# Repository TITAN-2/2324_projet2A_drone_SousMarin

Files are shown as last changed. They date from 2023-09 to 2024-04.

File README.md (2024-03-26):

# Projet de Drone Sous-marin - TITAN II - 2e Année ENSEA

## Description du Projet

Ce projet de deuxième année d'école d'ingénieur en électronique informatique vise à concevoir et développer un drone sous-marin contrôlable à distance. L'objectif de ce projet est de récupérer des objets dans le fond de l'étang de Cergy : plus précisement des lunettes de plongée. 
Le drone sera équipé de deux moteurs submersibles afin de propulser l'ensemble sous l'eau, de différents capteurs explicités plus tard, de seringues en guise de ballast, et finalement d'une STM32 couplée a une Raspeberry Pi. 

Le drone sera équipé de capteurs de pression et d'une centrale inertielle, connectés à une carte STM32. La communication entre les capteurs, les moteurs et les utilisateurs sera gérée par la STM32, tandis qu'une Raspberry Pi sera utilisée pour recevoir les informations des utilisateurs, héberger un serveur, et afficher une interface homme-machine (IHM) avec un flux vidéo provenant des caméras Pi.

## Fonctionnalités Principales

1. **STM32 pour la Gestion des Capteurs et des Moteurs**
   - La carte STM32 sera responsable de la communication avec les capteurs.
   - Elle assurera également le contrôle des moteurs en réponse aux commandes des utilisateurs.

2. **Raspberry Pi pour l'Interface Utilisateur**
   - La Raspberry Pi recevra les informations des utilisateurs.
   - Elle hébergera un serveur qui affichera le flux vidéo des caméras Pi et permettra aux utilisateurs d'envoyer des commandes au drone sous-marin.

3. **UART STM32 et la Raspberry Pi**
   - L'UART sera bidirectionnel
   - La Rasberry communiquera vers la STM32 les commandes utilisateurs reçu du serveur.
   - La STM32 communiquera vers la Raspberry les informations des différents capteurs (position, vitesse, niveau de batterie...)

## Configuration Matérielle

- **STM32**
  - Pin A0: PWM Moteur Gauche
  - Pin A1: PWM Moteur Droit
  - Pin RX: Reception de l'UART Raspberry
  - Pin TX: Transmission via UART vers Raspberry

- **Raspberry Pi**
  - A définir

- **Caméras Pi**
  - Voir le HowTo (a définir également)

## Installation et Exécution

1. Cloner le dépôt du projet sur la machine hôte.
   ```bash
   git clone https://github.com/votre-utilisateur/projet-drone-sous-marin.git
## Tester les parties indépendemments

[LA RECEPTION STM32](/RECEPTION_UART_H7A3ZIQ/HOWTO.md)

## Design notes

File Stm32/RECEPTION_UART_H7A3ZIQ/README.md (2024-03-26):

# TESTER LA RECEPTION STM32

## Installation de minicom
### Pour MAC
Installation avec HomeBrew :

```
brew install minicom
exec zsh
```

## Utilisation de minicom
 - **Envoie** de symbole, ici on se connecte au Raspberry Pi : 
```
minicom -b 115200 -o -D /dev/ttyS0 
```
>[!NOTE]
>Vous pouvez envoyer des commandes personnaliser avec  `echo 'votre message' < /dev/ttyS0`

 - **Reception** de symbole, ici sur le terminal connecter a la STM32
```
minicom -b 115200 -D /dev/tty.usbmodem1303
```
>[!NOTE]
> Remplacer le .usbmodem1303 par ce qui convient

## BRANCHEMENT SUR STM32
### SUR LA H7A3
On banche raspberry (TX : pin 6) sur la STM32 (RX : PD0, uart4)

## DETAILS DE COMMUNICATION
### RECEPTION | Procédure "maison"
On recoit un message de 8 octet de la forme:
- 2 bits : Check Header --> 0xFFFE
- 1 bit : Check Length --> 8
- 5 bits : Message --> thrust | angle | depth | paquetNumber
- 1 bit : Check Sum --> méthode XOR
- x bits : RPI Response --> Renvoie un message de confirmation ou non à la Raspberry

```
stty -F /dev/ttyS0 115200
echo -ne "\xFF\xFE\x09\x53\x1A\x64\x10\xFF\xCB" > /dev/ttyS0
```
```
stty -F /dev/ttyS0 115200
echo -ne "\xFF\xFE\x09\x53\x2D\x64\x10\xFF\xFD" > /dev/ttyS0
```
### RECEPTION | DYNAMIXEL 2.0
- [ ] https://github.com/TITAN-2/2324_projet2A_drone_SousMarin/issues/2
> Réaliser le même protocole que celui possiblement utilisé par les servo-moteurs. 1 pierre 2 coups.

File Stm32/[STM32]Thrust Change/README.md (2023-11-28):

# Modifier le thrust des moteurs

## Description 

Le but est de pouvoir modifier la puissance des moteurs controlés par un ASC, pour cela on envoie un PWM de rapport cyclique variant.
Il existe un protocole pour démarrer les ASC : 

**Start Protocole**

 - Envoyer un signal périodique créneaux de 50Hz avec un temps haut de 1ms, cela doit correspondre à notre rapport cyclique le plus faible ie \alpha = 0
 - Envoyer ce signal durant 1s
 - Modifier, ensuite, le temps haut à 2ms, cela correspond à notre rapport cyclique le plus élevée ie \alpha = 1
 - Envoyer ce signal durant 1s

**End Protocole**

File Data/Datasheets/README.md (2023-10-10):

# 2324_projet2A_drone_sous-marin

Poids à vide de la structure du sous-marin : 891 grammes

Point de flotaison de la structure du sous-marin : 3,120kg

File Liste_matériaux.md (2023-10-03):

Liste matériaux
- seringues 50 mL x4
- moteur

- caméra
- LED

- batteries NimH

- cylindre PVC

- STM32
- Raspberry

- Propulseur

- Capteurs pression hydraulique
- Capteur de proximité laser
- Capteur de température
- Centrale inertielle

- bouée avec MODEM
- Téléphone

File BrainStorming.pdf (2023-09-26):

Ébauche du cahier des charges:

- Énergie limité car syst embarqué
- Immersion du module donc étanchéité nécessaire
- Appareil pour récupérer un masque
- Sûrement une caméra à prévoir

Liens utiles:

Projet Sous-Marin ECAM (https://www.instructables.com/ECAM-Submarine/)

Question:

Structure à imprimer en 3D → Comment créer les fichiers à communiquer à l'imprimante 3D :

Cahier des charges:
- Construire un sous marin;
- Être capable d’avancer dans l’eau;
- Gérer la profondeur du drone;
- Contrôler les mouvements du drone;
- Être commandable depuis la terre ferme;
- Transmettre des informations (vidéo, profondeur) du drone vers la terre ferme
- Récupérer les lunettes de Monsieur Fiack au fond des étangs.

Contraintes:
- Milieu dans lequel est le drone: Eau (étanchéité);
- Rocher au fond, algues;
- Poids du sous marin (le faire remonter);
- Pression;
- Faible propagation des OEM;
- Capture vidéo + Faible luminosité au fond de l’étang;
- Transmission vidéo (direct, faible latence);
●

Les objectifs envisagés face à ces contraintes:

- Rendre le drone étanche et solide;

- Gérer la profondeur pour éviter rocher et algues;
- Connaître le point d’équilibre pour faire remonter le robot;
- Contrôler que les éléments qui résistent à la pression de l’eau;
- Gérer la communication entre le drone et nous;
- Gérer la consommation en énergie et comment transmettre l’énergie
- Éclairer le fond des étangs et capturer avec une caméra le fonds des étangs;
- Gérer la transmission vidéo en direct;

Solutions technologique:
- Choix des matériaux + cylindre si impression 3D: Pas plexiglasse car risque explosion;
- Pour le faire couler: Ballastes pour gérer la profondeur et l’équilibre autour du cylindre + sable au fond du sous marin pour qu’il reste droit et qu’il coule.
- Gyroscope pour gérer l’équilibre du drone
- Accéléromètre pour gérer la vitesse
- Laser ou capteur de pression ou de position pour gérer l’altitude
- Partie Énergique: mettre une batterie dans le sous marin;
- Pour le faire avancer: Hélices présentent sur l’ancien robot, aimants, pompes aquarium
- Pour le faire remonter: Ballons avec Timer ou Corde.
- Connexion entre nous et le drone: Bouée attachée au robot avec antenne réceptrice ou ondes radios (sonnar).
- Contrôler les mouvements du drone: PCB + Raspberry Pi avec un code pour d’abord que le drone fasse 10m.
- Trouver les lunettes de Monsieur Fiack: Caméra + Bras articulé ou crochet.
- Éclairer le fond des étangs: LED

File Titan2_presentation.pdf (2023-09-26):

# TITAN

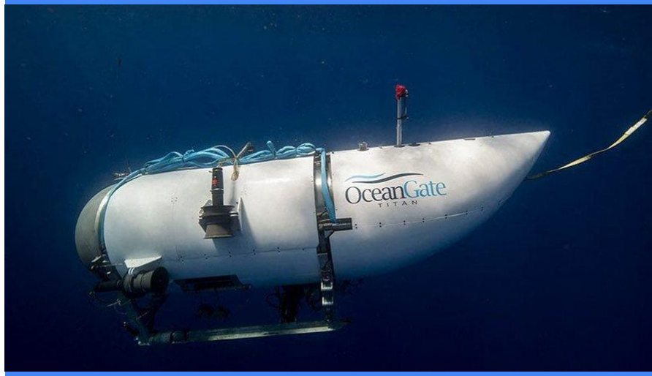
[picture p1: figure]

# Le drone Sous Marin qui ne

prendra pas l’eau.

II

# INTRODUCTION

2

# INTRODUCTION

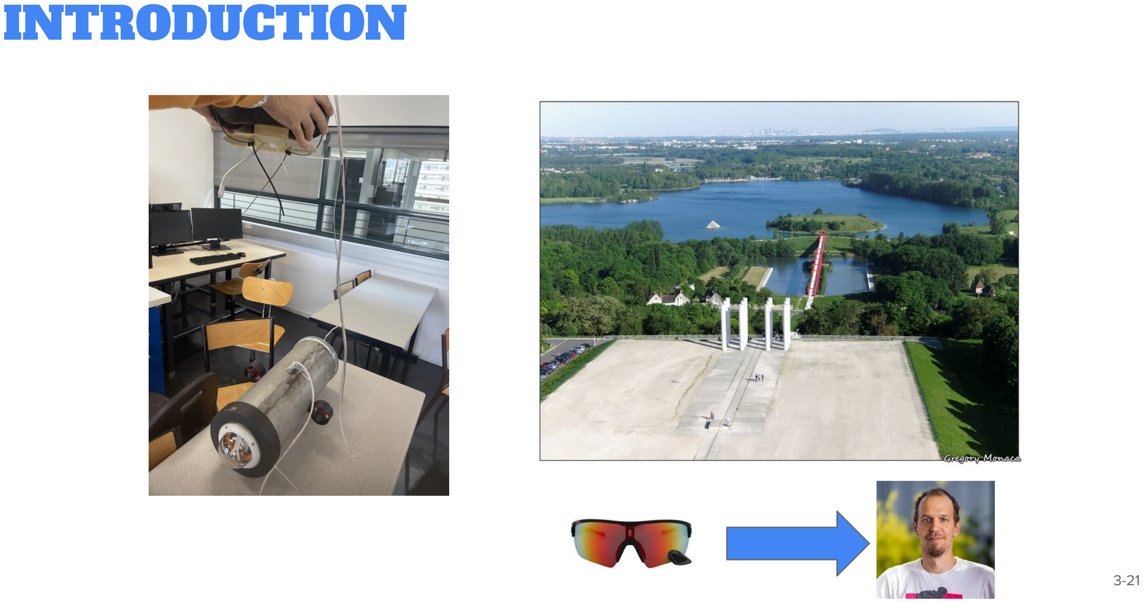
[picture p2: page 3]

# ÉTAT DE L’ART

4

# ÉTAT DE L’ART

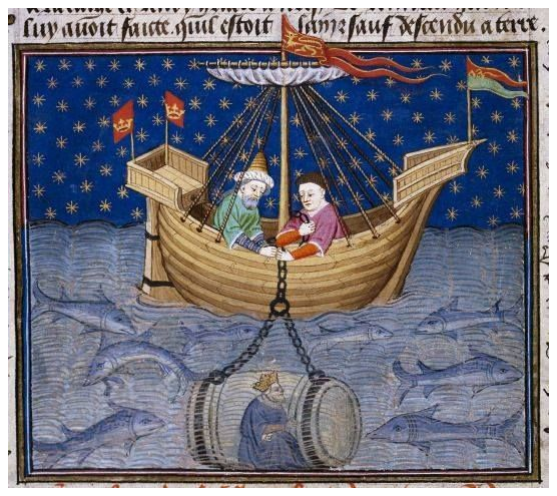
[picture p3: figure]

### 1ère cloche à plonger : tonneau d’Alexandre

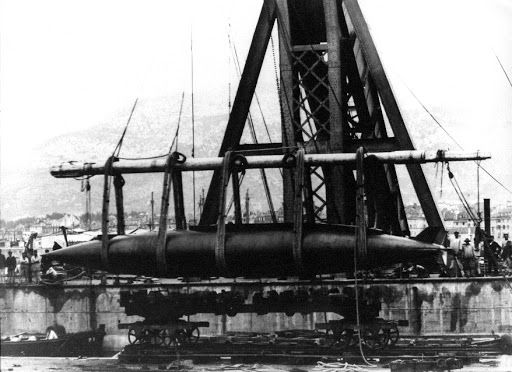
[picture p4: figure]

### 1887: Le gymnote, premier vrai sous-marin propulsé par un moteur électrique de 50 chevaux, atteint 8 noeuds en surface, 4 en plongée

### 1904: Le Narval, équipé d’un périscope et de ballasts externes,équipé d’une

propulsion mixte: machine à vapeur en surface, moteur électrique en plongée.

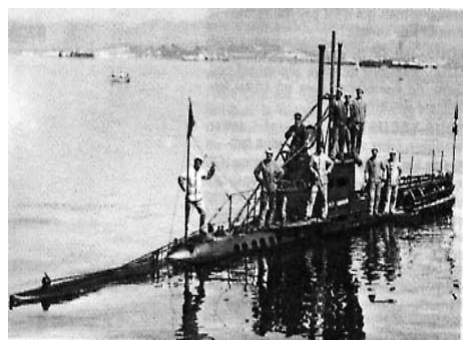
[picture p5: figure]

### 1914: Les submersibles fonctionnant grâce à une propulsion Diesel-électrique Une

batterie d’accumulateurs alimente un moteur électrique de propulsion.

1950: La propulsion nucléaire apparaît à bord des sous-marins,

# ÉTAT DE L’ART

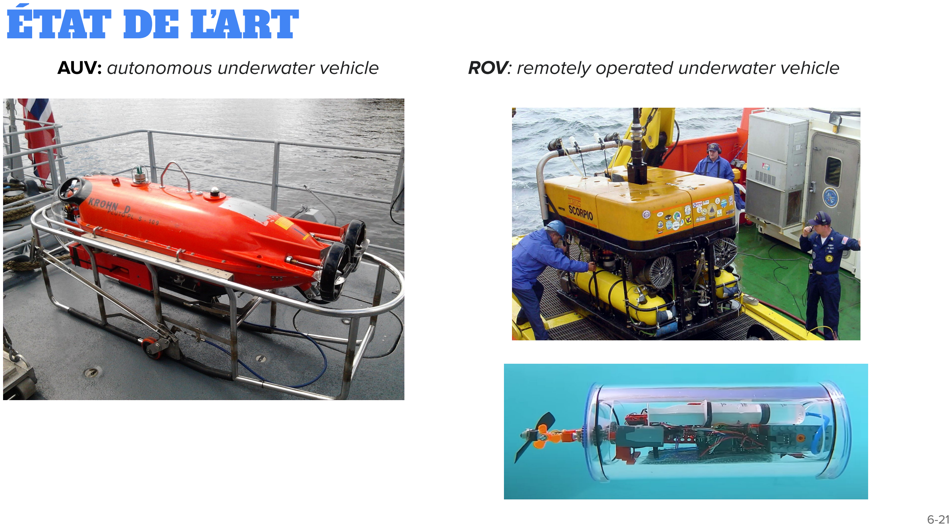
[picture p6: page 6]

AUV: autonomous underwater vehicle | ROV: remotely operated underwater vehicle

# CAHIER DES CHARGES

7

# CAHIER DES CHARGES

Fonctionnalités | Contraintes
F1 Être un système embarqué | Énergie limitée
F1.1 Être capable d’avancer dans l’eau | Milieu aquatique
F1.2 Gérer la profondeur du drone | C1 Présence de rocher au fond et d’algues C2 Poids du sous marin C3 Pression
F1.3 Être commandable depuis la terre ferme | C1 Faible propagation dans l’eau des OEM C2 Allure et orientation du drone variable

F2 Récupérer les lunettes de Monsieur Fiack au fond des étangs

F2.1 Visualiser le fond des étangs | C1 Capture vidéo C2 Faible luminosité au fond de l’étang

F2.2 Transmettre des informations du drone vers la terre
ferme

C1 Transmission vidéo en direct (ou faible latence)
C2 Transmission de multiple type de donnée (profondeur,
vitesse…) | 8-21

# OBJECTIFS ENVISAGÉS

9

# OBJECTIFS ENVISAGÉS

Contraintes | Objectifs
Énergie limitée | Choisir une source d’énergie adéquat Limiter l’utilisation de matériel énergivore
Milieu aquatique | Rendre le drone étanche
C1 Présence de rocher au fond et d’algues C2 Poids du sous marin C3 Pression | Connaître la profondeur de navigation Maîtriser le point de flottaison Utiliser des matériaux capable de supporter une légère pression
C1 Faible propagation dans l’eau des OEM C2 Allure et orientation du drone variable | Communiquer au drone des instructions intelligibles Connaître la vitesse et la position angulaire du drone
C1 Capture vidéo C2 Faible luminosité au fond de l’étang | Capturer le fonds des étangs Éclairer le fond des étangs
C1 Transmission vidéo en direct (ou faible latence) C2 Transmission de multiple type de donnée (profondeur, vitesse) | Communiquer à l’utilisateur des données en direct

# SOLUTIONS TECHNOLOGIQUES

11

# SOLUTIONS TECHNOLOGIQUES

OBJECTIFS CONCERNÉS : | Choisir une source d’énergie adéquat

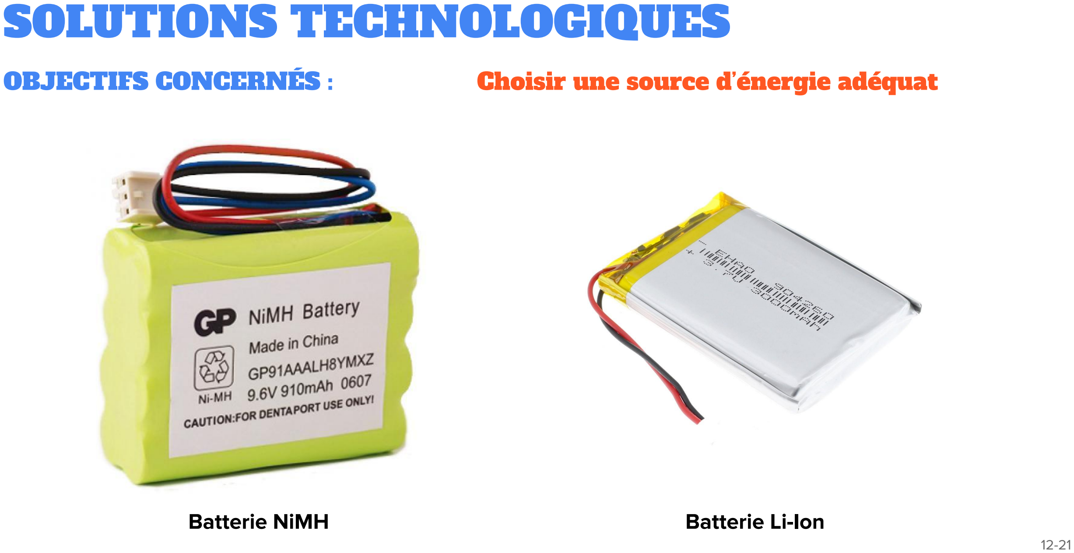
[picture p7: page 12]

Batterie NiMH | Batterie Li-Ion

# SOLUTIONS TECHNOLOGIQUES

OBJECTIFS CONCERNÉS : | Rendre le drone étanche & Utiliser des matériaux capable de supporter une légère pression

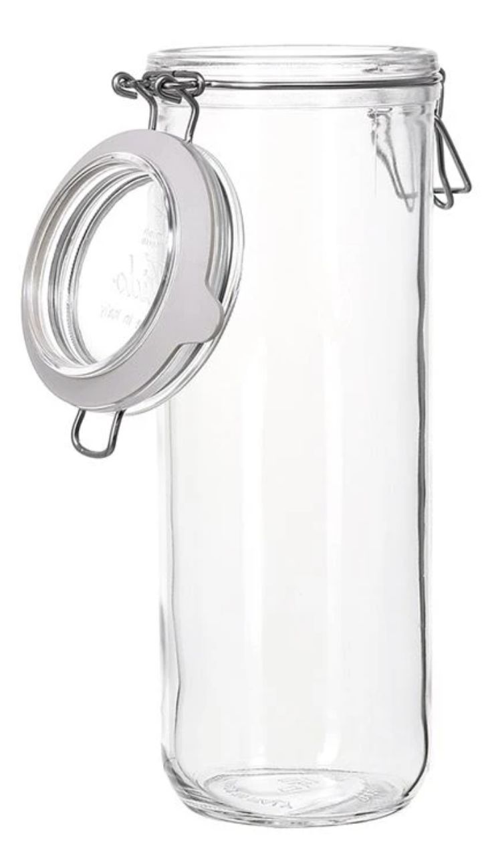
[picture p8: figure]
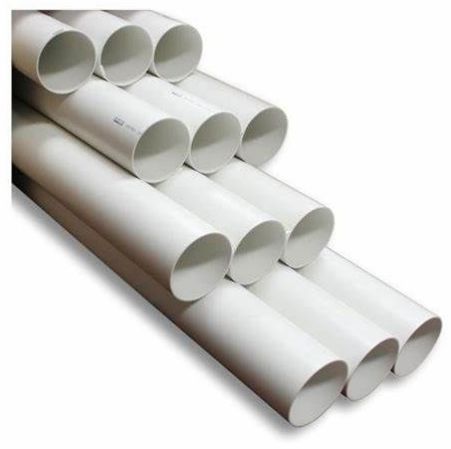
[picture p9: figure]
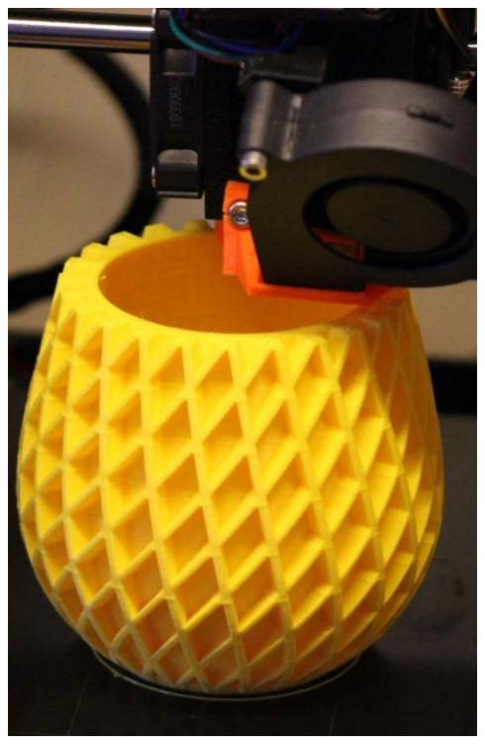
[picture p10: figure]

Bocal couvercle mécanique | PVC | Impression 3D

# SOLUTIONS TECHNOLOGIQUES

OBJECTIFS CONCERNÉS : | Connaître la profondeur de navigation

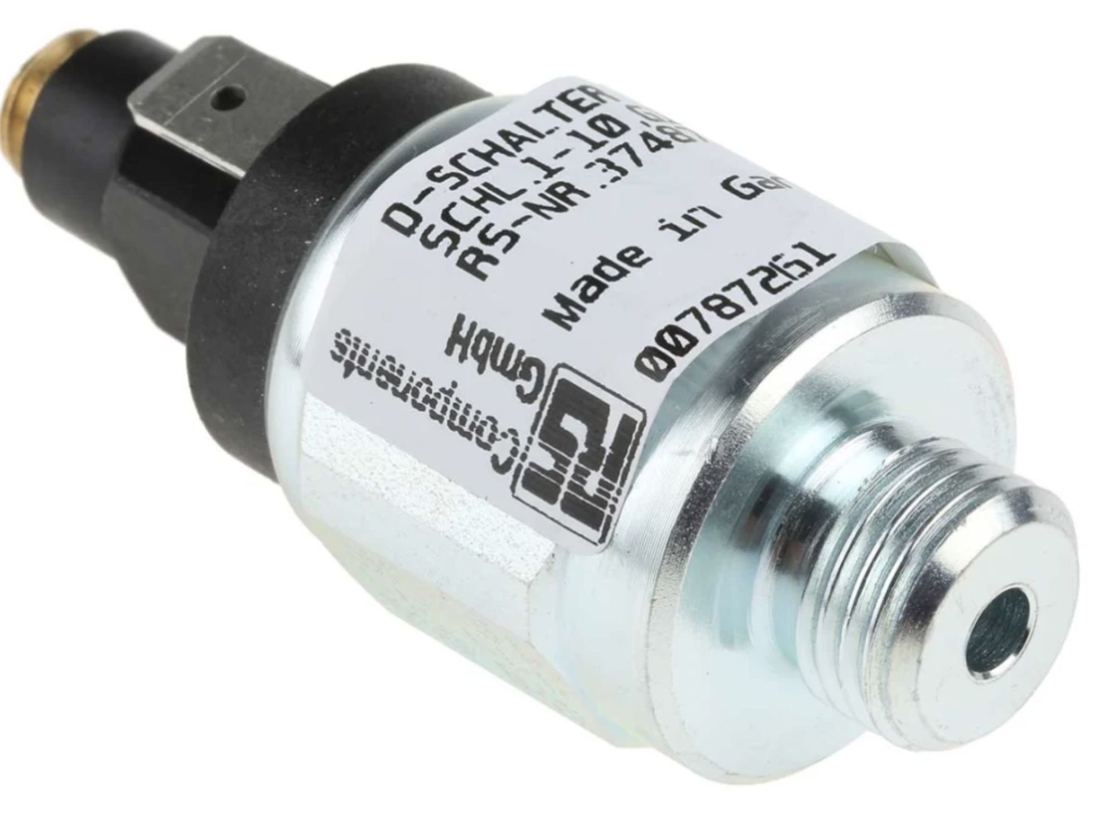
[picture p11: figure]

### Capteur pression hydraulique

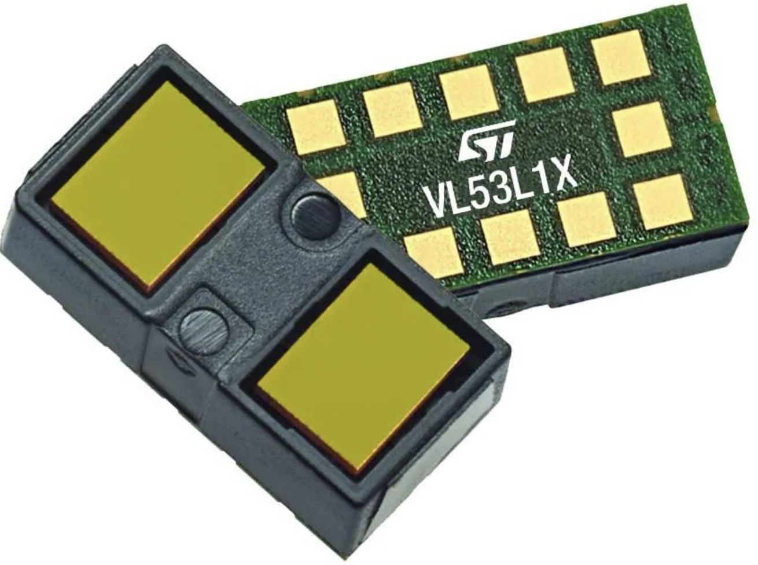
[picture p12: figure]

### Capteur de proximité laser

# SOLUTIONS TECHNOLOGIQUES

OBJECTIFS CONCERNÉS : | Faire avancer le drone sous-marin

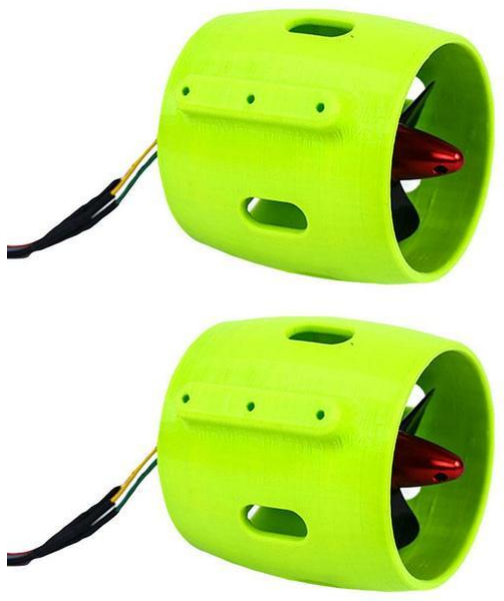
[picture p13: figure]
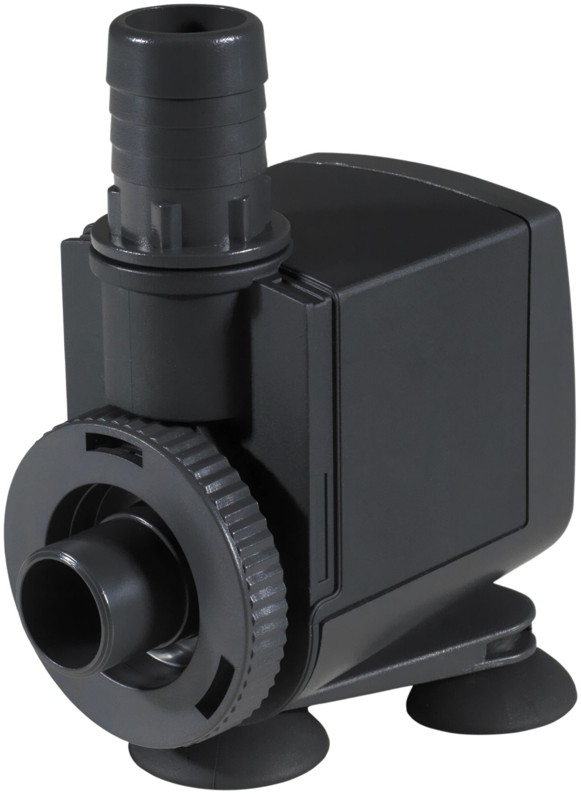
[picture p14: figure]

Propulseur sous marin | Pompe aquarium

# SOLUTIONS TECHNOLOGIQUES

OBJECTIFS CONCERNÉS : | Maîtriser le point de flottaison

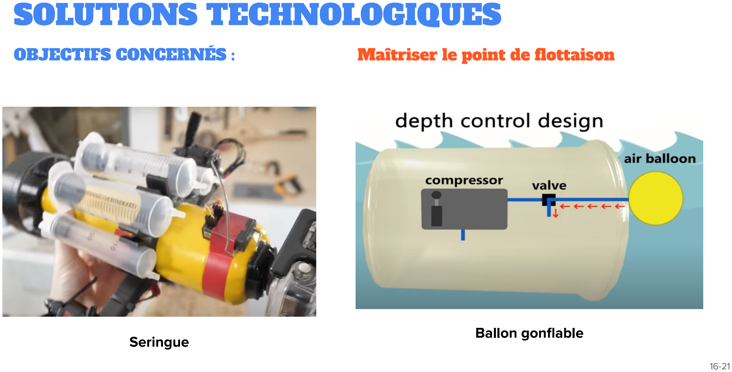
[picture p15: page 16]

### Seringue

### Ballon gonflable

# SOLUTIONS TECHNOLOGIQUES

# OBJECTIFS CONCERNÉS : Connaître la vitesse et la position angulaire du drone

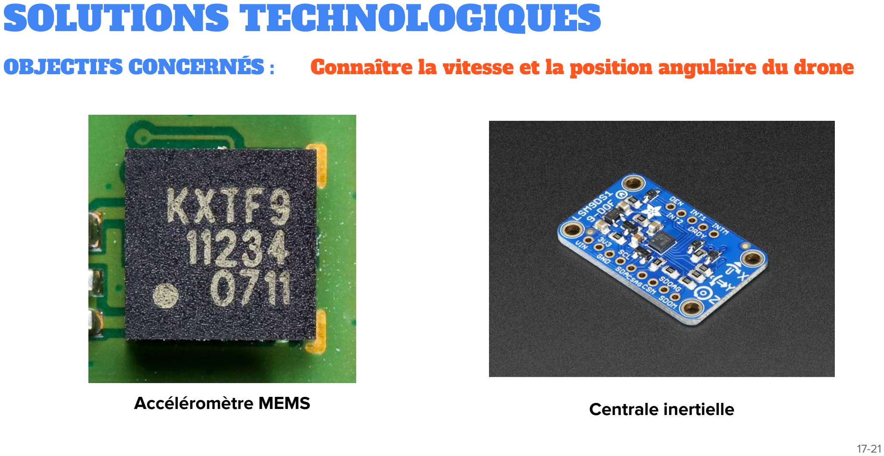
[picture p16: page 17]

Accéléromètre MEMS | Centrale inertielle

# SOLUTIONS TECHNOLOGIQUES

OBJECTIFS CONCERNÉS : | Capturer le fond des étangs

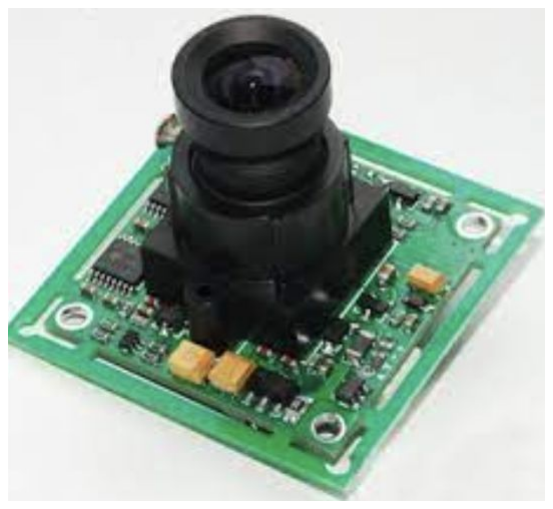
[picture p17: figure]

### STM32 Caméra

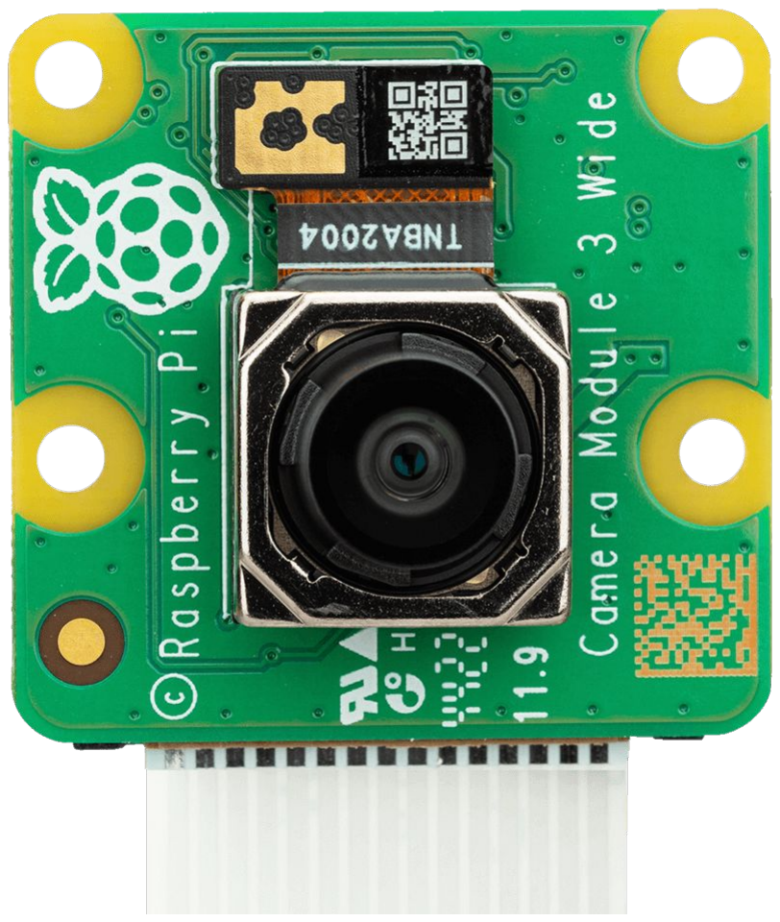
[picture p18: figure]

### Raspberry Pi Camera Mobile

# SOLUTIONS TECHNOLOGIQUES

OBJECTIFS CONCERNÉS : | Éclairer le fond des étangs

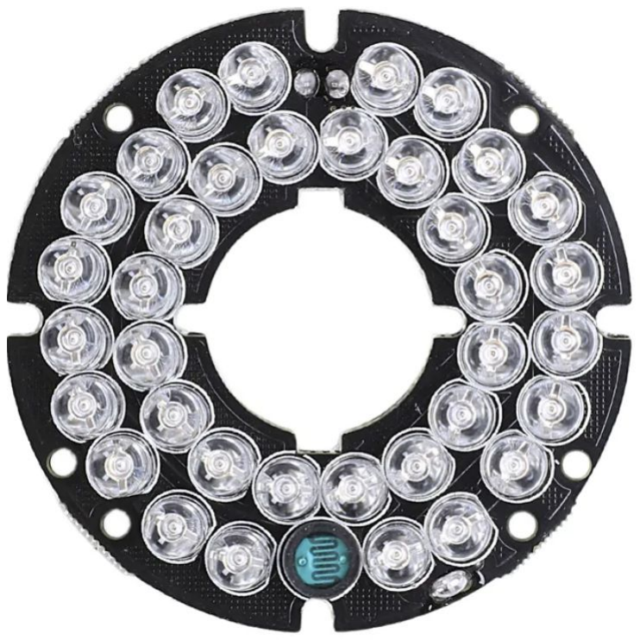
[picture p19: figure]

### Bandeau LEDs

# SOLUTIONS TECHNOLOGIQUES

# OBJECTIFS CONCERNÉS : Communiquer à l’utilisateur des données en direct &

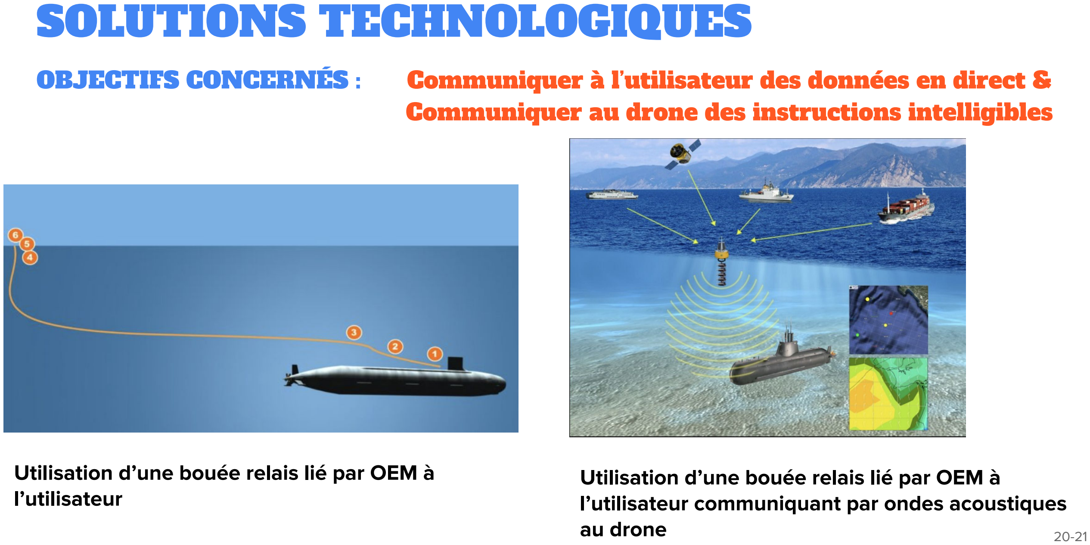
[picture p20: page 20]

# Communiquer au drone des instructions intelligibles

### Utilisation d’une bouée relais lié par OEM à l’utilisateur

### Utilisation d’une bouée relais lié par OEM à l’utilisateur communiquant par ondes acoustiques au drone

# RÉPARTITION

21

# RÉPARTITION

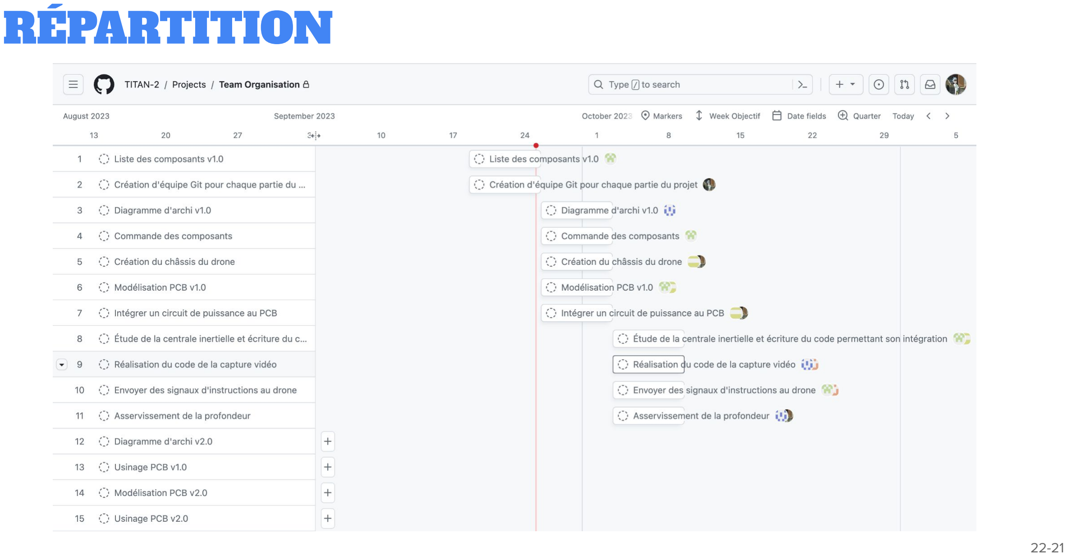
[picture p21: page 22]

# CONCLUSION

23

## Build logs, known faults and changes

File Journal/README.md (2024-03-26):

Week 1 : Debut du projet

Cahier des charges :

    Fonctionnalités :
        - Être un système embarqué :
            - Être capable d'avancer dans l'eau
            - Gérer la profondeur du drone
            - Être commandable depuis la terre ferme
        - Récupérer les lunettes de Monsieur Fiack au fond des étangs :
            - Visualiser le fond des étangs
            - Transmettre des informations du drone vers la terre ferme
    
    Contraintes :
        - Énergie limitée
            - Milieu aquatique

            - Présence de rocher au fond et d’algues
            - Poids du sous marin
            - Pression

            - Faible propagation dans l’eau des OEM
            - Allure et orientation du drone variable
        - 
            - Capture vidéo
            - Faible luminosité au fond de l’étang

            - Transmission vidéo en direct (ou faible latence)
            - Transmission de multiple type de donnée (profondeur, vitesse…)

Week 2:
891 grammes

Week 3 : 

- On a récupéré le tube en PVC collé et rempli de sable par M. PAPAZOGLOU, puis on a trouvé la masse nécesaire pour que l'on se retrouve au point de flotaison : 3,120kg
- On s'est également penché sur la manière de faire avancer le sous-marin dans l'eau, comparant les prix entre les hélices sur le côté ou une hélice arrière commandée par un aimant qui tourne.

24/10/2023

Pierre/Alexandre : Établir une connection ssh avec la RaspBerry Pi.

À faire : Établir un flux vidéo

07/11/2023

Pierre/Alexandre/Maëna : 

Mise au point de la prise de photos avec la RaspBerry Pi et début de recherches pour faire un flux vidéo.
Début d'avancée sur le flux vidéo. Problème : frame = None alors qu'il devrait avoir les images permettant de faire la vidéo.

À faire : corriger cette erreur pour obtenir la vidéo.

23/01/2024:
La vidéo est réglée
La communication UART entre Raspberry et STM32 est réussie
Le PCB est en cours de réalisation pour régler les cpateurs et la communication entre les composants
Le mouvement à l'intérieur des seringues est en cours de réalisation, pour gérer la profondeur du Sous Marin.
Il reste à faire:
1- Finir le PCB
2- Finir les mouvements à l'intérieur des seringues
3- Une fois fini faire le code des capteurs pour le faire apparaitre sur le site web
4- Gérer la propulsion lorsque qu'on modifie les joysticks (Lien entre Joystick -> Raspberry -> STM32-> Propulseurs)
5- Gérer la profondeur en modifiant les joysticks (Lien entre Joystick-> Raspberry -> STM32 ->Moteur Seringues)
6- Gérer les batteries, Création batterie (BSM, Relier toutes les cellules entre elles)
7- Tout mettre dans le Sous-Marin
8- Mettre les billes de plombs
9- Lien entre le sous marin et dehors (Lapin)

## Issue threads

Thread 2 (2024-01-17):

Coder le DYNAMIXEL Protocle pour l'échange UART

romingodelfuego, 2024-01-17:
Un gain de temps pour le développement de la communication serait un protocole de communication identique pour chaque communication entre les appareils.

SOURCE : https://emanual.robotis.com/docs/en/dxl/protocol2/

Closed 2024-03-19.

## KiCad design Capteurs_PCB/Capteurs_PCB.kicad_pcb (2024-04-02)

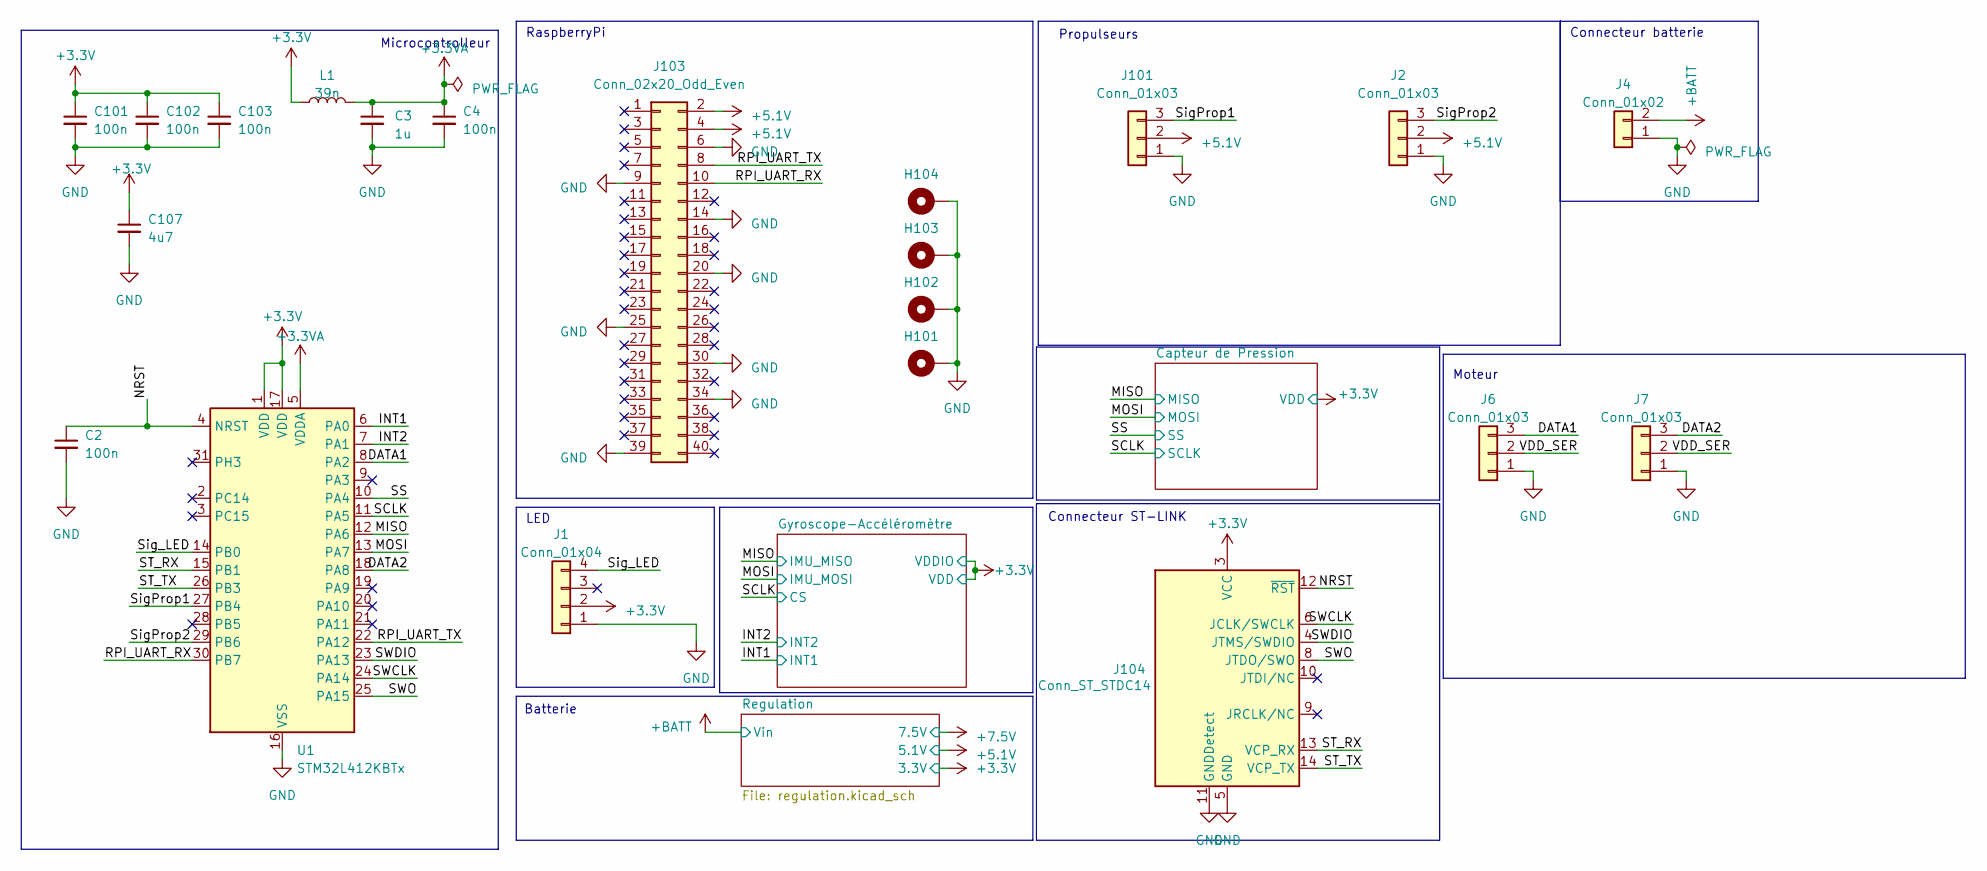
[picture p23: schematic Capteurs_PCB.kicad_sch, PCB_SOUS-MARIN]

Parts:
C2, C4, C101, C102, C103: 100n; C_0603_1608Metric_Pad1.08x0.95mm_HandSolder
C3: 1u; C_0603_1608Metric_Pad1.08x0.95mm_HandSolder
C107: 4u7; C_0603_1608Metric_Pad1.08x0.95mm_HandSolder
H101, H102, H103, H104: MountingHole_Pad; MountingHole_3.2mm_M3_DIN965_Pad
J1: Conn_01x04; JST_XH_B4B-XH-A_1x04_P2.50mm_Vertical
J2, J6, J7, J101: Conn_01x03; JST_XH_B3B-XH-A_1x03_P2.50mm_Vertical
J4: Conn_01x02; AMASS_XT60-M_1x02_P7.20mm_Vertical
J103: Conn_02x20_Odd_Even; PinSocket_2x20_P2.54mm_Vertical
J104: Conn_ST_STDC14; PinHeader_2x07_P1.27mm_Vertical_SMD
L1: 39n; L_0805_2012Metric_Pad1.05x1.20mm_HandSolder
U1: STM32L412KBTx; LQFP-32_7x7mm_P0.8mm

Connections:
+3.3V: C101.1, C102.1, C103.1, C107.1, J1.2, J104.3 (VCC), L1.1, U1.1 (VDD), U1.17 (VDD); also elsewhere on the board
+3.3VA: C3.1, C4.1, L1.2, U1.5 (VDDA)
+5V: J2.2, J101.2, J103.2, J103.4; also elsewhere on the board
+BATT: J4.2; also elsewhere on the board
/DATA1: J6.3, U1.8 (PA2)
/DATA2: J7.3, U1.18 (PA8)
/INT1: U1.6 (PA0); also elsewhere on the board
/INT2: U1.7 (PA1); also elsewhere on the board
/MISO: U1.12 (PA6); also elsewhere on the board
/MOSI: U1.13 (PA7); also elsewhere on the board
/NRST: C2.1, J104.12 (~RST), U1.4 (NRST)
/RPI_UART_RX: J103.10, U1.30 (PB7)
/RPI_UART_TX: J103.8, U1.22 (PA12)
/SCLK: U1.11 (PA5); also elsewhere on the board
/SS: U1.10 (PA4); also elsewhere on the board
/ST_RX: J104.13 (VCP_RX), U1.15 (PB1)
/ST_TX: J104.14 (VCP_TX), U1.26 (PB3)
/SWCLK: J104.6 (JCLK/SWCLK), U1.24 (PA14)
/SWDIO: J104.4 (JTMS/SWDIO), U1.23 (PA13)
/SWO: J104.8 (JTDO/SWO), U1.25 (PA15)
/SigProp1: J101.3, U1.27 (PB4)
/SigProp2: J2.3, U1.29 (PB6)
/Sig_LED: J1.4, U1.14 (PB0)
/VDD_SER: J6.2, J7.2
GND: C2.2, C3.2, C4.2, C101.2, C102.2, C103.2, C107.2, H101.1, H102.1, H103.1, H104.1, J1.1, J2.1, J4.1, J6.1, J7.1, J101.1, J103.6, J103.9, J103.14, J103.20, J103.25, J103.30, J103.34, J103.39, J104.5 (GND), J104.7 (GND), J104.11 (GNDDetect), U1.16 (VSS), U1.32 (VSS); also elsewhere on the board

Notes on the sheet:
Microcontrolleur
Batterie
Moteur
Connecteur batterie
LED
Connecteur ST-LINK
RaspberryPi
Propulseurs

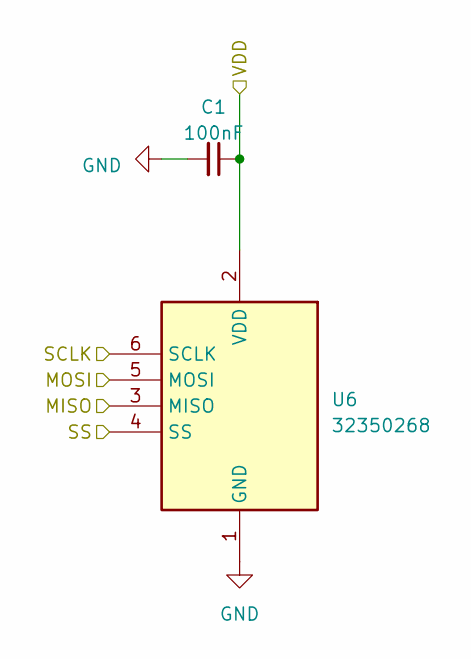
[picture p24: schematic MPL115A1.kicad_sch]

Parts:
C1: 100nF; C_0603_1608Metric_Pad1.08x0.95mm_HandSolder
U6: 32350268; Pressure_Captor_Custom

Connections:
+3V3: C1.1, U6.2 (VDD); also elsewhere on the board
/MISO: U6.3 (MISO); also elsewhere on the board
/MOSI: U6.5 (MOSI); also elsewhere on the board
/SCLK: U6.6 (SCLK); also elsewhere on the board
/SS: U6.4 (SS); also elsewhere on the board
GND: C1.2, U6.1 (GND); also elsewhere on the board

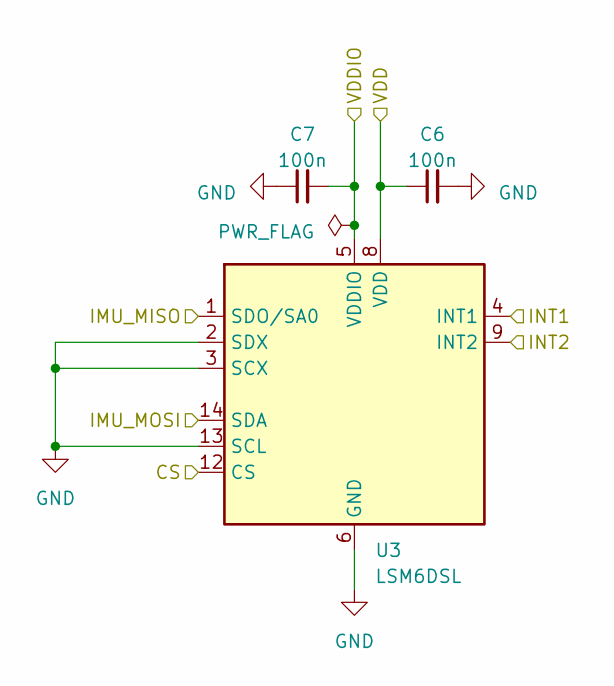
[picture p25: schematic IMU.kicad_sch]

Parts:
C6, C7: 100n; C_0603_1608Metric_Pad1.08x0.95mm_HandSolder
U3: LSM6DSL; LGA-14_3x2.5mm_P0.5mm_LayoutBorder3x4y

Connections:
+3V3: C6.1, C7.2, U3.5 (VDDIO), U3.8 (VDD); also elsewhere on the board
/INT1: U3.4 (INT1); also elsewhere on the board
/INT2: U3.9 (INT2); also elsewhere on the board
/MISO: U3.1 (SDO/SA0); also elsewhere on the board
/MOSI: U3.14 (SDA); also elsewhere on the board
/SCLK: U3.12 (CS); also elsewhere on the board
GND: C6.2, C7.1, U3.2 (SDX), U3.3 (SCX), U3.6 (GND), U3.7 (GND), U3.13 (SCL); also elsewhere on the board

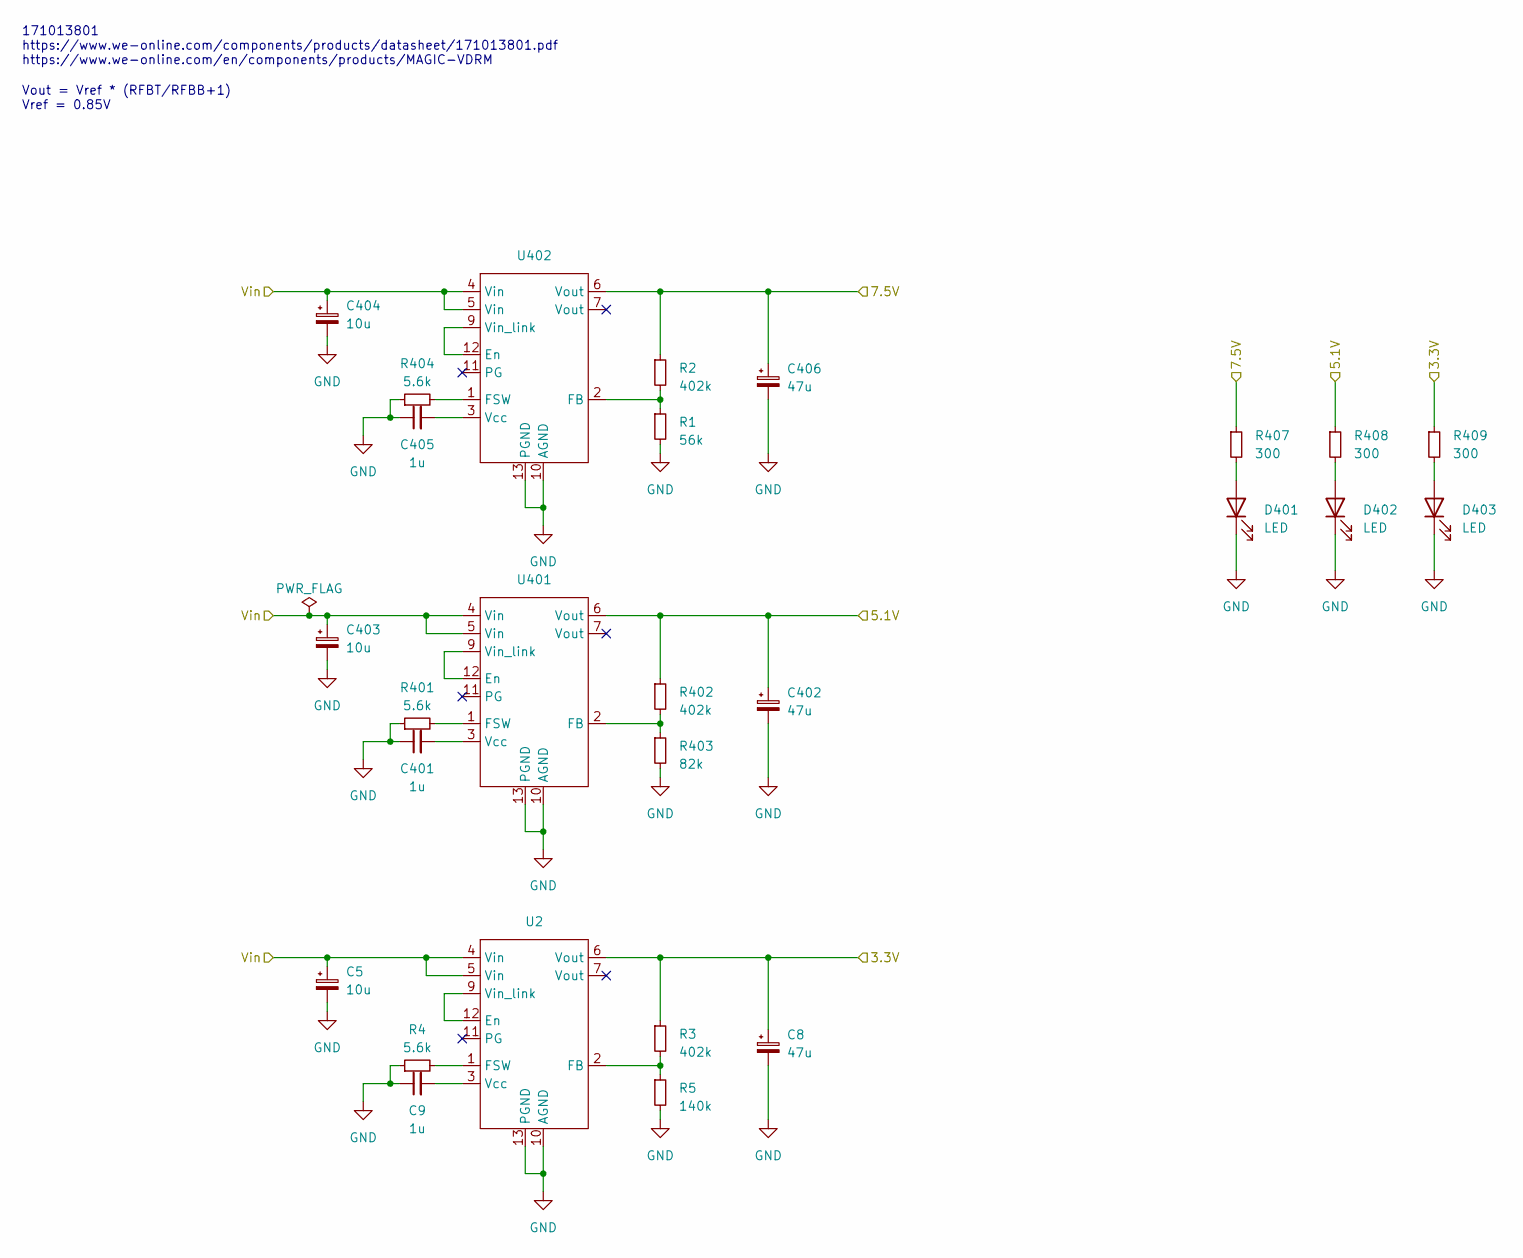
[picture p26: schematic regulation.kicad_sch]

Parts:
C5, C403, C404: 10u; CP_Elec_5x5.4; MPN 865060542002
C8, C402, C406: 47u; CP_Elec_6.3x5.4; MPN 865060543005
C9, C401, C405: 1u; C_0603_1608Metric_Pad1.08x0.95mm_HandSolder
D401, D402, D403: LED; LED_0402_1005Metric_Pad0.77x0.64mm_HandSolder
R1: 56k; R_0603_1608Metric_Pad0.98x0.95mm_HandSolder
R2, R3, R402: 402k; R_0603_1608Metric_Pad0.98x0.95mm_HandSolder
R4, R401, R404: 5.6k; R_0603_1608Metric_Pad0.98x0.95mm_HandSolder
R5: 140k; R_0603_1608Metric_Pad0.98x0.95mm_HandSolder
R403: 82k; R_0603_1608Metric_Pad0.98x0.95mm_HandSolder
R407, R408, R409: 300; R_0603_1608Metric_Pad0.98x0.95mm_HandSolder
U2, U401, U402: Regulator; MPN 171013801

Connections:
+3.3V: C8.1, R3.1, R409.1, U2.6 (Vout); also elsewhere on the board
+5V: C402.1, R402.1, R408.1, U401.6 (Vout); also elsewhere on the board
+7.5V: C406.1, R2.1, R407.1, U402.6 (Vout)
+BATT: C5.1, C403.1, C404.1, U2.4 (Vin), U2.5 (Vin), U401.4 (Vin), U401.5 (Vin), U402.4 (Vin), U402.5 (Vin); also elsewhere on the board
GND: C5.2, C8.2, C9.1, C401.1, C402.2, C403.2, C404.2, C405.1, C406.2, D401.1 (K), D402.1 (K), D403.1 (K), R1.2, R4.1, R5.2, R401.1, R403.2, R404.1, U2.10 (AGND), U2.13 (PGND), U401.10 (AGND), U401.13 (PGND), U402.10 (AGND), U402.13 (PGND); also elsewhere on the board
unnamed: D401.2 (A), R407.2
unnamed: D402.2 (A), R408.2
unnamed: D403.2 (A), R409.2
unnamed: U2.9 (Vin_link), U2.12 (En)
unnamed: R3.2, R5.1, U2.2 (FB)
unnamed: R4.2, U2.1 (FSW)
unnamed: C9.2, U2.3 (Vcc)
unnamed: U401.9 (Vin_link), U401.12 (En)
unnamed: R402.2, R403.1, U401.2 (FB)
unnamed: R401.2, U401.1 (FSW)
unnamed: C401.2, U401.3 (Vcc)
unnamed: U402.9 (Vin_link), U402.12 (En)
unnamed: R1.1, R2.2, U402.2 (FB)
unnamed: R404.2, U402.1 (FSW)
unnamed: C405.2, U402.3 (Vcc)

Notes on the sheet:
Vout = Vref * (RFBT/RFBB+1) Vref = 0.85V
171013801 https://www.we-online.com/components/products/datasheet/171013801.pdf https://www.we-online.com/en/components/products/MAGIC-VDRM

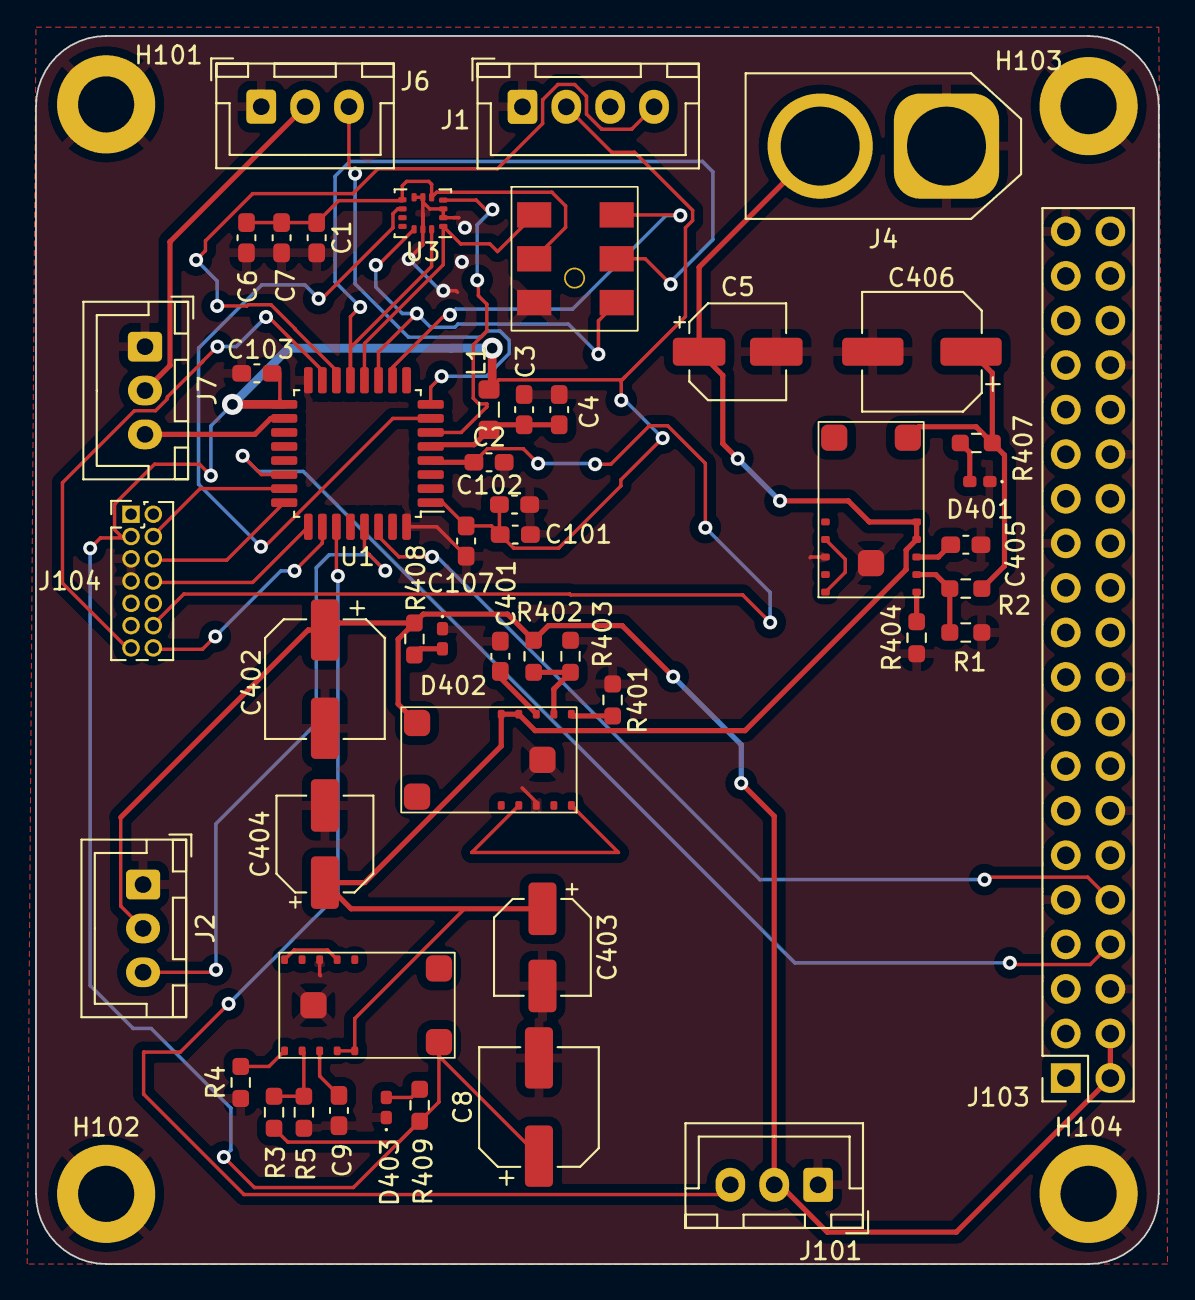
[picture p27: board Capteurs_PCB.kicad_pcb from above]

Board: 2 copper layers, 64.0 x 70.0 mm, 53 parts (0 on the bottom side), 42 nets.

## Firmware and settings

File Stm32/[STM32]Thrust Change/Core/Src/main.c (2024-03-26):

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
/* Includes ------------------------------------------------------------------*/
#include "main.h"


TIM_HandleTypeDef htim2;

void SystemClock_Config(void);
static void MX_GPIO_Init(void);
static void MX_USB_OTG_HS_USB_Init(void);
static void MX_TIM2_Init(void);
/**
  * @brief  The application entry point.
  * @retval int
  */
int main(void)
{
  /* MCU Configuration--------------------------------------------------------*/

  /* Reset of all peripherals, Initializes the Flash interface and the Systick. */
  HAL_Init();

  /* Configure the system clock */
  SystemClock_Config();

  /* Initialize all configured peripherals */
  MX_GPIO_Init();
  MX_USB_OTG_HS_USB_Init();
  MX_TIM2_Init();
  /* USER CODE BEGIN 2 */
  int valeur;
	HAL_TIM_PWM_Start(&htim2, TIM_CHANNEL_1);
	HAL_TIM_PWM_Start(&htim2, TIM_CHANNEL_2);

	__HAL_TIM_SET_COMPARE(&htim2, TIM_CHANNEL_1, 50);
	__HAL_TIM_SET_COMPARE(&htim2, TIM_CHANNEL_2, 50);

	HAL_Delay(1000);
  	valeur=100;
  	__HAL_TIM_SET_COMPARE(&htim2, TIM_CHANNEL_1, 100);
	__HAL_TIM_SET_COMPARE(&htim2, TIM_CHANNEL_2, 100);
	HAL_Delay(1000);


  /* USER CODE END 2 */

  /* Infinite loop */
  /* USER CODE BEGIN WHILE */
 	 valeur=50;
  	int coeff=1;

	while (1)
	{
    /* USER CODE END WHILE */

    /* USER CODE BEGIN 3 */
		if (valeur<101 && valeur>49){


			__HAL_TIM_SET_COMPARE(&htim2, TIM_CHANNEL_1, valeur);
			__HAL_TIM_SET_COMPARE(&htim2, TIM_CHANNEL_2, valeur);

			HAL_Delay(100);
		}
		else{
			coeff=coeff*-1;
		}
		valeur = valeur + coeff;

	}
  /* USER CODE END 3 */
}

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


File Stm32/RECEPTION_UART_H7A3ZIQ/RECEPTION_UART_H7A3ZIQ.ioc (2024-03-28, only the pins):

Mcu.UserName=STM32H7A3ZITxQ
PA0.Signal=UART4_TX
PA10.GPIO_Label=USB_FS_ID [ZX62RD-AB-5P8_ID]
PA10.Signal=USB_OTG_HS_ID
PA11.GPIO_Label=USB_FS_N [USBLC6-2SC6_IO_1]
PA11.Signal=USB_OTG_HS_DM
PA12.GPIO_Label=USB_FS_P [USBLC6-2SC6_IO_2]
PA12.Signal=USB_OTG_HS_DP
PA2.Signal=USART2_TX
PA3.Signal=USART2_RX
PA5.Signal=S_TIM2_CH1_ETR
PA9.GPIO_Label=USB_FS_VBUS  [ZX62RD-AB-5P8_VBUS]
PA9.Signal=USB_OTG_HS_VBUS
PB0.GPIO_Label=LD1 (Green Led)
PB0.Signal=GPIO_Output
PB10.Signal=S_TIM2_CH3
PB14.GPIO_Label=LD3 (Red Led)
PB14.Signal=GPIO_Output
PC13.GPIO_Label=B1 (Blue PushButton)
PC13.Signal=GPIO_Input
PC14-OSC32_IN.GPIO_Label=OSC32_IN
PC14-OSC32_IN.Signal=RCC_OSC32_IN
PC15-OSC32_OUT.GPIO_Label=OSC32_OUT
PC15-OSC32_OUT.Signal=RCC_OSC32_OUT
PD0.Signal=UART4_RX
PD8.GPIO_Label=STLINK_RX
PD8.Signal=USART3_TX
PD9.GPIO_Label=STLINK_TX
PD9.Signal=USART3_RX
PE1.GPIO_Label=LD2 (Yellow Led)
PE1.Signal=GPIO_Output
PF10.GPIO_Label=USB_FS_PWR_EN [STMPS2141STR_EN]
PF10.Signal=GPIO_Output
PG7.GPIO_Label=USB_FS_OVCR  [STMPS2141STR_FAULT]
PG7.Signal=GPXTI7
PH0-OSC_IN.GPIO_Label=PH0-MCU
PH0-OSC_IN.Signal=RCC_OSC_IN
PH1-OSC_OUT.GPIO_Label=PH1-MCU
PH1-OSC_OUT.Signal=RCC_OSC_OUT

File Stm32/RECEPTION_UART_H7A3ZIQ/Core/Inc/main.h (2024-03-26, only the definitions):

#define B1_Pin GPIO_PIN_13
#define B1_GPIO_Port GPIOC
#define OSC32_IN_Pin GPIO_PIN_14
#define OSC32_IN_GPIO_Port GPIOC
#define OSC32_OUT_Pin GPIO_PIN_15
#define OSC32_OUT_GPIO_Port GPIOC
#define USB_FS_PWR_EN_Pin GPIO_PIN_10
#define USB_FS_PWR_EN_GPIO_Port GPIOF
#define PH0_MCU_Pin GPIO_PIN_0
#define PH0_MCU_GPIO_Port GPIOH
#define PH1_MCU_Pin GPIO_PIN_1
#define PH1_MCU_GPIO_Port GPIOH
#define LD1_Pin GPIO_PIN_0
#define LD1_GPIO_Port GPIOB
#define LD3_Pin GPIO_PIN_14
#define LD3_GPIO_Port GPIOB
#define STLINK_RX_Pin GPIO_PIN_8
#define STLINK_RX_GPIO_Port GPIOD
#define STLINK_TX_Pin GPIO_PIN_9
#define STLINK_TX_GPIO_Port GPIOD
#define USB_FS_OVCR_Pin GPIO_PIN_7
#define USB_FS_OVCR_GPIO_Port GPIOG
#define USB_FS_VBUS_Pin GPIO_PIN_9
#define USB_FS_VBUS_GPIO_Port GPIOA
#define USB_FS_ID_Pin GPIO_PIN_10
#define USB_FS_ID_GPIO_Port GPIOA
#define USB_FS_N_Pin GPIO_PIN_11
#define USB_FS_N_GPIO_Port GPIOA
#define USB_FS_P_Pin GPIO_PIN_12
#define USB_FS_P_GPIO_Port GPIOA
#define LD2_Pin GPIO_PIN_1
#define LD2_GPIO_Port GPIOE

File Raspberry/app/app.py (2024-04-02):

# /app/app.py

from flask import Flask, render_template, Response, request
from streaming.server import StreamingHandler, StreamingServer
from streaming.camera import StreamingOutput
import threading
from picamera2 import Picamera2,Preview
from picamera2.encoders import JpegEncoder
from picamera2.outputs import FileOutput
import serial  
import RPi.GPIO as GPIO
import json
import os
import fileinput

app = Flask(__name__)
uart_port = serial.Serial('/dev/ttyS0', baudrate=115200, timeout=1)

@app.route('/')
def index():
    return render_template('index.html')

def generate():
    while True:
        frame = output.frame
        if frame is not None:
            yield (b'--frame\r\n'
                   b'Content-Type: image/jpeg\r\n\r\n' + frame + b'\r\n')

@app.route('/video_feed')
def video_feed():
    return Response(generate(),
                    mimetype='multipart/x-mixed-replace; boundary=frame')

def calculate_checksum_xor(data):
    checksum = 0
    for byte in data:
        checksum ^= int(byte, 16)
    return [format(checksum,"02X")]

# Route pour la mise à jour des valeurs via UART
paquetNumber = format(0x30,"02X")

@app.route('/update_values', methods=['POST'])
def update_values():
    global paquetNumber
    try: 
        vitesse = format(int(request.form['vitesse']),'02X') #Format HEX
        direction = format(int(request.form['direction']),'02X') #Format HEX
        profondeur = format(int(request.form['profondeur']),'02X') #Format HEX

        # Construire la commande UART à partir des valeurs reçues
        checkHeader= ["FF","FE"] #Format HEX
        command = [vitesse,direction,profondeur,paquetNumber]
        checkLength = [format(len(command)*2,'02X')]
        checkSum = calculate_checksum_xor(checkHeader+checkLength+command)
        # Envoyer la commande via UART
        uart_command =[int(item, 16) for sublist in [checkHeader, checkLength,command,checkSum] for item in sublist]
        uart_escaped=bytearray(uart_command)
        uart_port.write(uart_escaped)
        uart_port.flush()
        paquetNumber =format(int(paquetNumber,16)+1,"02X")
        return f'Send Success {uart_command} | {uart_escaped}'  # Réponse du serveur, peut être personnalisée
    except Exception as e:
        return f'Error: {str(e)}'

def read_byte():
    return int.from_bytes(uart_port.read(), byteorder='big')

def read_message():
    while True:
        byte = read_byte()
        if byte == 0xFF:  # Vérifie si le premier octet est FF
            next_byte = read_byte()
            if next_byte == 0xFE:  # Vérifie si le deuxième octet est FE
                message = bytearray([0xFF, 0xFE])  # Commence le message avec FF FE
                while True:
                    byte = read_byte()
                    if byte == 0xFF:  # Vérifie si le prochain octet est FF
                        next_byte = read_byte()
                        if next_byte == 0xFE:  # Vérifie si l'octet suivant est FE
                            # Fin du message, retourne le message lu
                            return message
                        else:
                            # Si ce n'est pas la fin du message, ajoute les octets au message
                            message += bytearray([0xFF, next_byte])
                    else:
                        # Ajoute les octets au message
                        message.append(byte)
def read_data():
    while True:
        offset_min,offset_max=3,1
        message = read_message().hex()
        message_list=[int(message[i:i+2],16) for i in range(0, len(message), 2)]
        print("Message reçu:", message)
        print("Message convertit:",[int(message[i:i+2],16) for i in range(offset_min, len(message)-offset_max, 2)])

        keys =["posX","posY","angleDelta","temperature","baterryPower"]
        dict_Js = {keys[i]: message_list[i] for i in range(len(keys))}
        print("dict_Js",dict_Js)
        data_js ,path_file_js= json.dumps(dict_Js),"app/static/js/data.js"
        with open(path_file_js,'w') as fichier_js:
            fichier_js.write("var donnees ={};".format(data_js))
            fichier_js.write("export default donnees;")




picam2 = Picamera2()
picam2.configure(picam2.create_video_configuration(main={"size": (640, 480)}))

# Configurez l'encodeur vidéo pour le format JPEG
output = StreamingOutput()
picam2.start_recording(JpegEncoder(), FileOutput(output))





try:
    address = ('', 8000)
    server = StreamingServer(address, StreamingHandler)

    flask_thread = threading.Thread(target=app.run, args=('0.0.0.0', 5000))
    print("Starting App thread...")
    flask_thread.start()
    
    uart_thread = threading.Thread(target=read_data)
    print("Starting UART thread...")
    uart_thread.start()
    if uart_thread.is_alive():
        print("UART thread is running.")
    else:
        print("UART thread failed to start or stopped unexpectedly.")

    server_thread = threading.Thread(target=server.serve_forever)
    print("Starting Server thread...")
    server_thread.start()

    flask_thread.join()
    server_thread.join()


finally:
    picam2.stop_recording()

if __name__ == '__main__':
    app.run(debug=True)

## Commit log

2023-09-26 Commit cahier des charges
2023-11-07 Update Journal de bord
2023-11-28 Maquette Figma pour l'intefrace H/M
    Ajout de la maquette qui dispose tous les éléments présents, cela facilitera la partie code HTML/CSS
2023-11-28 Add STM32 Thrust Change
    Ajout du projet STM32CubeIde permettant la modification de la puissance des moteurs
2023-11-28 Ajout d'une partie du code pour la réception
    Il manque la partie de décodage pour affecter au bonne fonction les bonnes valeurs
2023-12-05 2 styles de joysticks
2023-12-05 Code Flux video
    Code permettant de générer un flux vidéo (plutôt un flux de mjpg compressés) ayant pour adresse internet: 192.168.0.252:8000
2023-12-05 Ajout code stm32 Reception | Delete old Stm32 Reception | Organize Send Raspberry
2023-12-12 Update Control.html en intégrant les codes css et javascript
2024-01-16 Début PCB
    [Capteurs_PCB.kicad_pcb, Capteurs_PCB.kicad_sch]
2024-01-16 Reception STM32
    Possible maintenant de recevoir un signal de la Raspberry et de le print sur un Serial Plotter
2024-01-22 update kicad
    [IMU.kicad_sch, MPL115A1.kicad_sch, STM32L476RG.kicad_sch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]
2024-01-22 Avancement Process STM32
2024-01-22 Avancement sur la partie process
2024-01-23 Modification PCB
2024-01-23 PCB changement
    Pcb changé (Raspberry))
    [Capteurs_PCB.kicad_sch, MPL115A1.kicad_sch, STM32L476RG.kicad_sch]
2024-01-23 Datasheet
    Datasheet des capteurs et de la STM32 utilisés pour le PCB
2024-01-23 pcb update
    [Capteurs_PCB.kicad_sch, IMU.kicad_sch, MPL115A1.kicad_sch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]
2024-01-24 uptdate PCB
    [Capteurs_PCB.kicad_sch, STM32L476RG.kicad_sch]
2024-01-30 Raspberry UPDATE
    [pyvenv.cfg]
2024-01-30 updates pcb
    [Capteurs_PCB.kicad_sch, IMU.kicad_sch, MPL115A1.kicad_sch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]
2024-02-05 Modif seringues pcb
    [Capteurs_PCB.kicad_sch]
2024-02-06 [Working] STM32 Process
2024-02-06 modif kicad
    [Capteurs_PCB.kicad_sch]
2024-02-06 update pcb
    [Capteurs_PCB.kicad_sch, IMU.kicad_sch, MPL115A1.kicad_sch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]
2024-02-06 Factorisation de la V1 + Ajout d'un test UART
2024-02-06 Modif PCB
    [Capteurs_PCB.kicad_sch, IMU.kicad_sch, MPL115A1.kicad_sch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]
2024-02-14 Petites modifications erreurs sur PCB
2024-02-17 updates kicad
2024-02-17 kicad changes and starting footprints
    [Capteurs_PCB.kicad_sch, IMU.kicad_sch, MPL115A1.kicad_sch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]
2024-02-26 Changement pour éviter de tout casser
2024-02-26 Changement interrupteur
    [Capteurs_PCB.kicad_sch, IMU.kicad_sch, regulation.kicad_sch]
2024-02-26 ST-LINK sur Kicad
    [Capteurs_PCB.kicad_sch, IMU.kicad_sch, MPL115A1.kicad_sch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]
2024-02-27 Enlever les erreurs Kicad+Mettre connecteur batterie
    [Capteurs_PCB.kicad_sch, IMU.kicad_sch, regulation.kicad_sch]
2024-03-03 Empreintes
    A revoir car pas sur pour certaines + faire celles des composants modifiés
    [Capteurs_PCB.kicad_sch, MPL115A1.kicad_sch, regulation.kicad_sch]
2024-03-05 Empreintes modifiées
    [Capteurs_PCB.kicad_sch, IMU.kicad_sch, MPL115A1.kicad_sch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]
2024-03-05 Footprint design and Footprint assignment
    [Capteurs_PCB.kicad_pcb, Capteurs_PCB.kicad_sch, MPL115A1.kicad_sch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]
2024-03-05 Start routage
    [Capteurs_PCB.kicad_pcb]
2024-03-05 Update routage
    [Capteurs_PCB.kicad_pcb, Capteurs_PCB.kicad_sch]
2024-03-05 Routage en cours
    [Capteurs_PCB.kicad_pcb, Capteurs_PCB.kicad_sch, IMU.kicad_sch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]
2024-03-07 Suite placement des composants pour routage
2024-03-11 Début de routage
    [Capteurs_PCB.kicad_pcb, Capteurs_PCB.kicad_sch, regulation.kicad_sch]
2024-03-12 modifs kicad
2024-03-12 Problème réglé
    [Capteurs_PCB.kicad_pcb, Capteurs_PCB.kicad_sch, MPL115A1.kicad_sch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]
2024-03-12 Changement Label
    [Capteurs_PCB.kicad_sch]
2024-03-12 Suite PCB
    [Capteurs_PCB.kicad_pcb, Capteurs_PCB.kicad_sch, MPL115A1.kicad_sch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]
2024-03-12 Ajout des requetes pour sendUart
2024-03-13 Add POE Injector
    [Capteurs_PCB.kicad_sch, MPL115A1.kicad_sch, regulation.kicad_sch]
2024-03-14 Le routage continue
    [Capteurs_PCB.kicad_pcb]
2024-03-17 Avancement PCB mais encore des problèmes
    [Capteurs_PCB.kicad_pcb, Capteurs_PCB.kicad_sch]
2024-03-18 Derniers changements mais encore des erreurs
    [Capteurs_PCB.kicad_pcb]
2024-03-19 Pilotage des moteurs par joysticks [Fonctionnel]
2024-03-19 Ajout de l'envoie des données STM32
2024-03-19 Petit changement
    Explication du dernier commit:
    -Création d'un TIM3 cadencé a 1 Hz
    -Interrutpion TIM3 : envoie des données en uart des data Capteurs
    -Aucun capteur pour le moment on simule avec de fausses
    -Création du RPICom_SendBinaryMessage qui envoie vers Rasberry le bon format de donnée + vers huartDebug
2024-03-26 Modification du PCB
    [Capteurs_PCB.kicad_pcb, Capteurs_PCB.kicad_sch, regulation.kicad_sch]
2024-03-26 Correction des interruptions TIM3
    [Process.c, RECEPTION_UART_H7A3ZIQ.ioc, RPICom.c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]
2024-03-26 Receive uart and updates on web
2024-03-28 Fonctionnement des seringues avec XML320 !
2024-04-01 Finition et plus d'erreur sur le PCB
    [Capteurs_PCB.kicad_pcb]
2024-04-02 update raspberry
    [pyvenv.cfg]

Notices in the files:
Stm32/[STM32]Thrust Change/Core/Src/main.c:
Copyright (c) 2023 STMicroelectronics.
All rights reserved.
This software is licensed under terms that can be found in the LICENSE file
